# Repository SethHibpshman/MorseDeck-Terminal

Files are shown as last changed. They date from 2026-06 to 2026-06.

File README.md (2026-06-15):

# MorseDeck Terminal

> A standalone Morse code keyer and trainer built on the ESP32-S3, featuring real-time decoding, four keying modes, a rotary settings menu, and T9-style keyboard replay.

<p align="center">
  <a href="https://youtu.be/P0Hb8axpHqs">
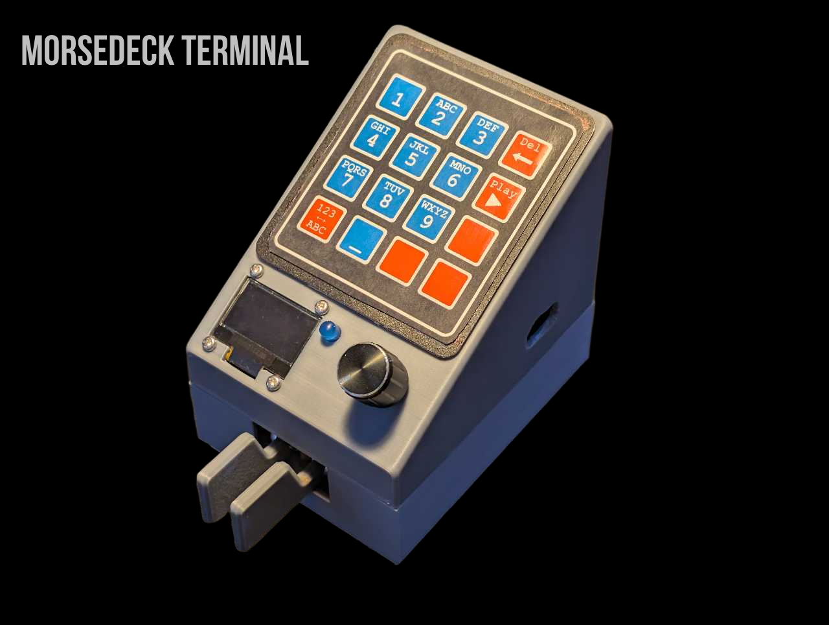
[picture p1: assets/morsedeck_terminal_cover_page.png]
Watch demo
    
  </a>
</p>

<p align="center">
  <a href="https://youtu.be/P0Hb8axpHqs">▶️ Watch the Full Demo</a>
</p>

> Full build documentation, hardware reference, and software notes are in the [project wiki](../../wiki). For an account of the technical challenges, design decisions, and lessons learned, see [Design Reflections](../../wiki/5.-Design-Reflections).

## Table of Contents

- [Overview](#overview)
- [Functionality](#functionality)
  - [Operating Modes](#operating-modes)
  - [Keying Modes](#keying-modes)
  - [Morse Decoding](#morse-decoding)
  - [Keyboard Replay Mode](#keyboard-replay-mode)
  - [Settings Menu](#settings-menu)
- [System Design](#system-design)
  - [Hardware](#hardware)
  - [PCB Design](#pcb-design)
  - [Software](#software)
- [Bill of Materials](#bill-of-materials)
- [Author](#author)
- [AI Disclosure](#ai-disclosure)
- [License](#license)

## Overview

MorseDeck Terminal is a fully self-contained Morse code keyer and trainer built on the ESP32-S3 and programmed in MicroPython. The device supports professional-grade iambic keying with automatic real-time decoding, a rotary encoder settings interface, multi-tap keyboard input, and serial output to an external display, all running on a custom PCB in a 3D-printed enclosure.

The project was designed and built from scratch for **EENG 163: Introduction to Embedded Systems** at Eastern Washington University, covering real-time signal generation, hardware input handling, OLED display rendering, and inter-device communication.

## Functionality

### Operating Modes

The device has three selectable operating modes, accessible from the settings menu:

| Mode | Description |
|---|---|
| **Sandbox** | Free-form keying with live decoding on the OLED |
| **Keyboard Replay** | Type text via keypad and play it back as Morse |
| **Debug** | Live readout of paddle state, encoder pins, keypad input, and memory |

### Keying Modes

Four keying styles are supported, covering both traditional and modern paddle techniques:

| Mode | Behavior |
|---|---|
| **Iambic A** | Alternates dit/dah while both paddles are held; stops on release |
| **Iambic B** | Same as A, but sends one extra element after both paddles are released |
| **Ultimatic** | Last-pressed paddle wins when both are held simultaneously |
| **Straight Key** | Either paddle held produces a continuous tone |

### Morse Decoding

Gap detection runs automatically in the background and scales with the live WPM setting:

- After **3x the dit duration** of paddle idle time, a letter space is inserted and the buffered sequence is decoded to the OLED
- After **7x the dit duration**, the space is upgraded to a word break

### Keyboard Replay Mode

Text can be entered using the 4x4 keypad with T9-style multi-tap input, following a standard phone keyboard layout. The device encodes the typed text to Morse in real time, displays it on the OLED, and plays it back through the buzzer on command.

| Key | Action |
|---|---|
| A | Backspace |
| B | Play current text as Morse |

### Settings Menu

Hold the rotary encoder button for **2 seconds** to open the settings menu. Short-press to enter edit mode on any item, then rotate to adjust.

| Setting | Options |
|---|---|
| Mode | Sandbox, Keyboard Replay, Debug |
| Keying Mode | Iambic A, Iambic B, Ultimatic, Straight Key |
| Volume | 0-10 |
| LED | Enabled / Disabled |
| Decoding | Enabled / Disabled |
| About | Scrolling credits page |
| Reset | Hard resets the device |

Additional behaviors include a typewriter-style boot screen on startup and a bouncing-logo screensaver after 60 seconds of inactivity.

## System Design

### Hardware

| Component | Details |
|---|---|
| Microcontroller | ESP32-S3 |
| Display | SSD1306 128x64 OLED (SoftI2C) |
| Paddles | 2x momentary buttons (Dit / Dah) |
| Keypad | 4x4 membrane matrix keypad |
| Rotary Encoder | CLK, DT, SW with long-press menu activation |
| Buzzer | Piezo PWM buzzer |
| LED | Single external indicator LED |

> Full pin mapping and wiring notes are in the [Hardware Reference](../../wiki/3.-Hardware-Reference) wiki page.

### PCB Design

Designed in KiCad. All project files are in [`/hardware/kicad_project_files`](/hardware/kicad_project_files).

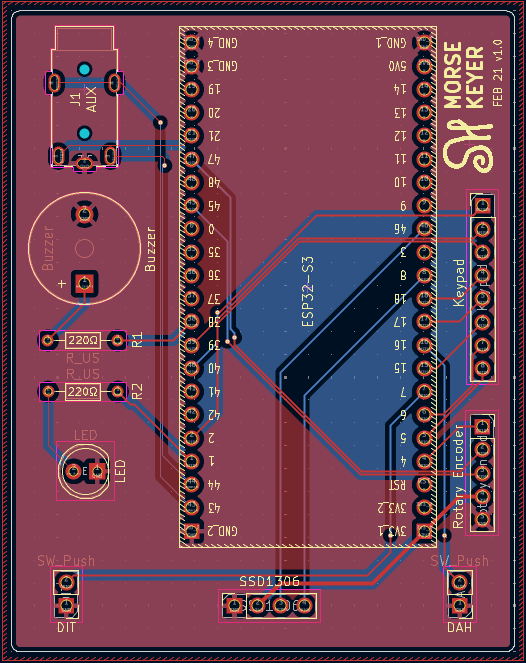
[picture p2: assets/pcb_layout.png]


### Software

Written entirely in **MicroPython** as a single-file application.

**Dependencies:** `ssd1306`, `gfx`, `keypad`, `urandom`

```
main.py    # Full application: hardware init, all functions, main loop
```

> Code structure, dependencies, and configuration details are in the [Software Reference](../../wiki/4.-Software-Reference) wiki page.

## Bill of Materials

| Item | Qty | Unit | Total |
|---|---|---|---|
| [ESP32-S3 Dev Board](https://a.co/d/08OKpdB2) | 1 | $6.40 | $6.40 |
| SSD1306 OLED 128x64 | 1 | $3.00 | $3.00 |
| Rotary Encoder | 1 | $3.00 | $3.00 |
| 4x4 Membrane Keypad | 1 | $1.60 | $1.60 |
| PCBs | 1 | - | $5.00 |
| Piezo Buzzer (Active) | 1 | $0.35 | $0.35 |
| Resistors | - | - | $0.12 |
| LED | 1 | $0.03 | $0.03 |
| 3D-printed enclosure | 1 | - | $0.00 |
| **Grand Total** | | | **$19.50** |

> - Unit costs reflect bulk purchasing; individual retail prices may be higher.
> - 3D printing assumes university or personal printer access.
> - PCB cost assumes overseas fabrication.

## Author

**Seth Hibpshman**  
Student of Electrical Engineering, Eastern Washington University

## AI Disclosure
_AI (LLM) tools were used for quality assurance review of the firmware and in the drafting and editing of this README and wiki documentation; all code was written by hand._

## License

[GNU General Public License v3.0](LICENSE)

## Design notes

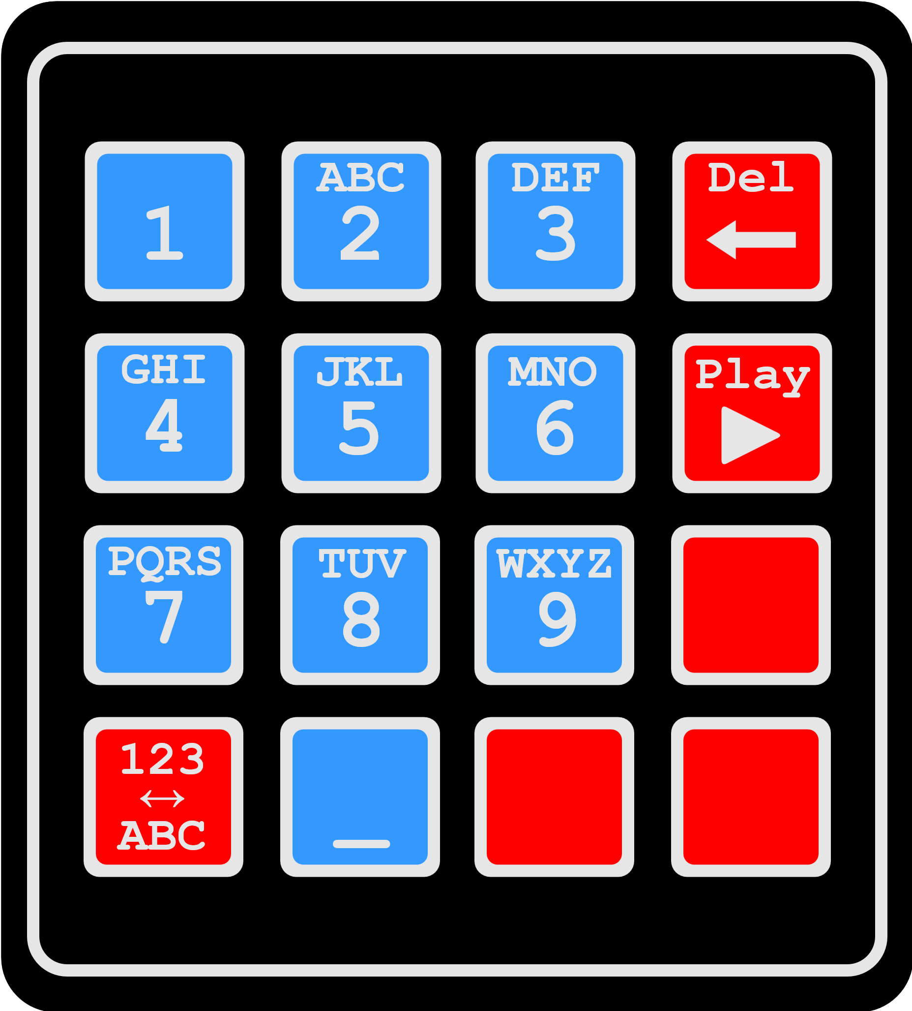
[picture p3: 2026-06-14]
assets/4x4_keypad_art/keypad 4x4.png

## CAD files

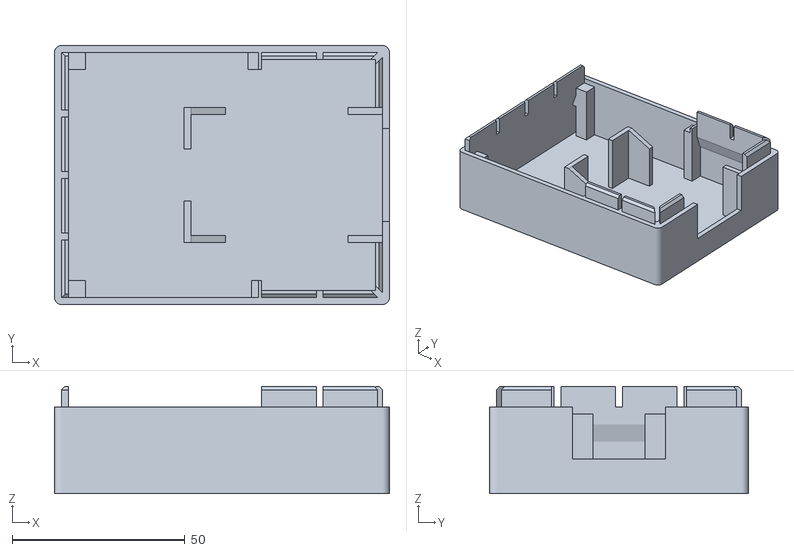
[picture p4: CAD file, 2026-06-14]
hardware/enclosure_model_files/MorseDeck Terminal Bottom Shell.stl
97.0 x 75.0 x 31.0

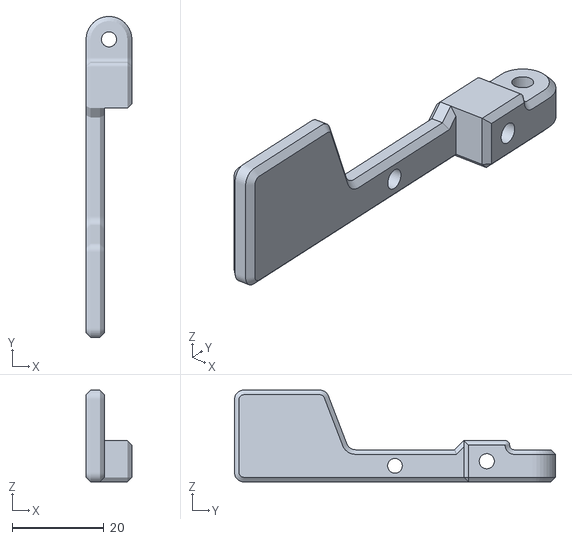
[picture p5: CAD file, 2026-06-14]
hardware/enclosure_model_files/paddle_assembly/paddles-right_lever_nospacer.stl
10.0 x 70.0 x 20.0

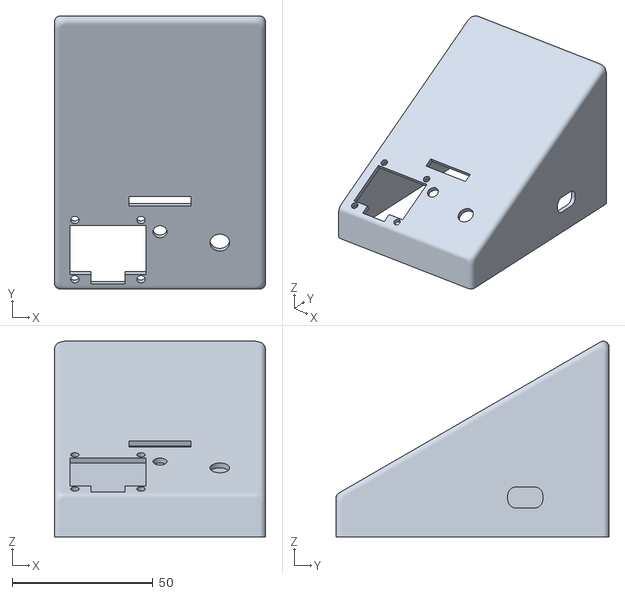
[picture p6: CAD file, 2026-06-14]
hardware/enclosure_model_files/MorseDeck Terminal Top Shell.stl
75.0 x 97.0 x 69.5

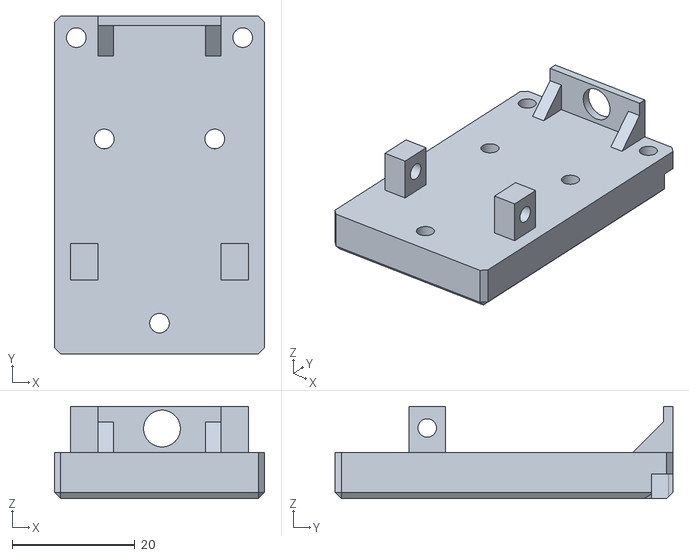
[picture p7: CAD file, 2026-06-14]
hardware/enclosure_model_files/paddle_assembly/paddles-base.stl
34.2 x 55.0 x 15.0

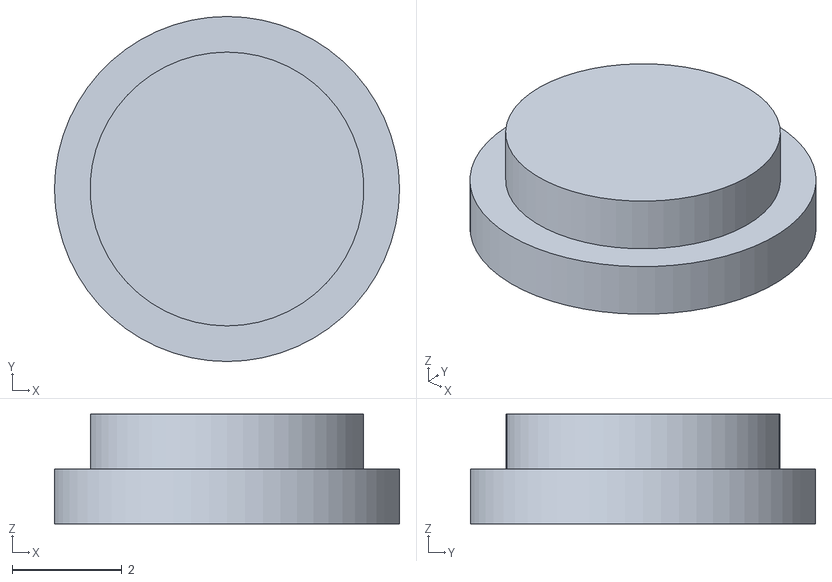
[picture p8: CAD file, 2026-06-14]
hardware/enclosure_model_files/paddle_assembly/paddles-spring_clip.stl
6.30 x 6.30 x 2.00

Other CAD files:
hardware/enclosure_model_files/paddle_assembly/paddles-left_lever_nospacer.stl
hardware/enclosure_model_files/Morse Keyer Top Shell.f3d
hardware/enclosure_model_files/MorseDeck Terminal Bottom Shell.f3d

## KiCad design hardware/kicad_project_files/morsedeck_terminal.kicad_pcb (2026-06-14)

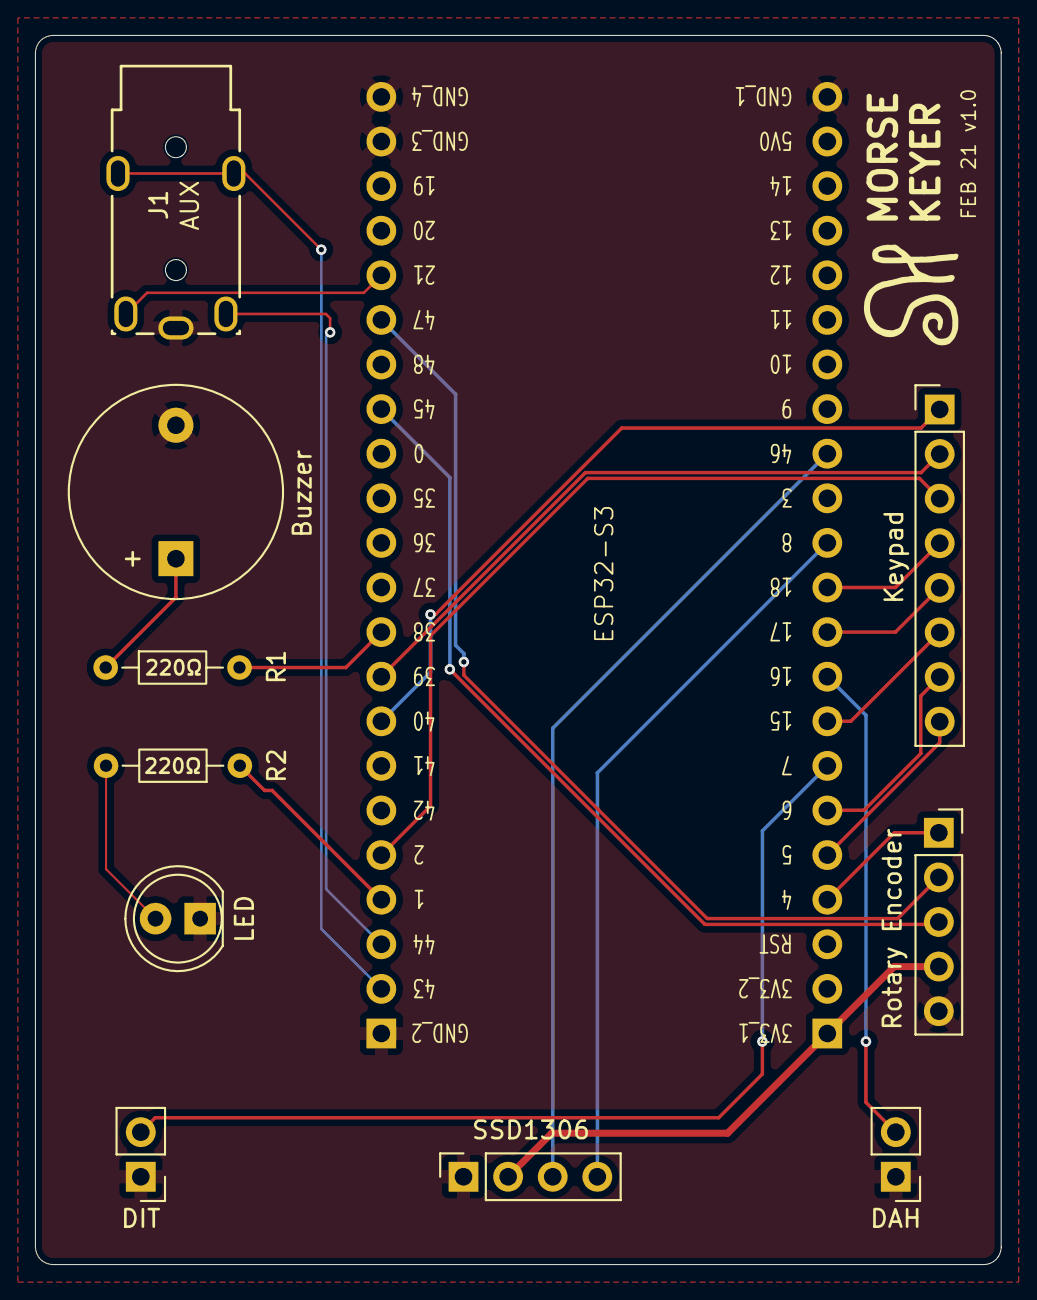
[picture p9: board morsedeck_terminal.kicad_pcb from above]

Board: 4 copper layers, 55.0 x 70.0 mm, 11 parts (0 on the bottom side), 24 nets.

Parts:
Buzzer: Buzzer_12x9.5RM7.6
DAH: SW_Push; PinHeader_1x02_P2.54mm_Vertical
DIT: SW_Push; PinHeader_1x02_P2.54mm_Vertical
ESP32-S3: ESP32-S3 Mount
J1: 3.5mm Aux Jack; 54-00174_TEN
Keypad: PinHeader_1x08_P2.54mm_Vertical
LED: LED; LED_D5.0mm
R1, R2: R_US; R_Axial_DIN0204_L3.6mm_D1.6mm_P7.62mm_Horizontal
Rotary Encoder: PinSocket_1x05_P2.54mm_Vertical
SSD1306: PinSocket_1x04_P2.54mm_Vertical

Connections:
+3V3: ESP32-S3.3V3_1 (3V3), Rotary Encoder.4 (+), SSD1306.2 (VCC)
/GPIO1: ESP32-S3.1 (GPIO1), R2.1
/GPIO2: ESP32-S3.2 (GPIO2), Keypad.3 (Col_2)
/GPIO4: ESP32-S3.4 (GPIO4), Rotary Encoder.1 (CLK)
/GPIO5: ESP32-S3.5 (GPIO5), Keypad.8 (Row_1)
/GPIO6: ESP32-S3.6 (GPIO6), Keypad.7 (Row_2)
/GPIO7: DIT.2, ESP32-S3.7 (GPIO7)
/GPIO8: ESP32-S3.8 (GPIO8), SSD1306.4 (SDA)
/GPIO15: ESP32-S3.15 (GPIO15), Keypad.6 (Row_3)
/GPIO16: DAH.2, ESP32-S3.16 (GPIO16)
/GPIO17: ESP32-S3.17 (GPIO17), Keypad.5 (Row_4)
/GPIO18: ESP32-S3.18 (GPIO18), Keypad.4 (Col_1)
/GPIO21: ESP32-S3.21 (GPIO21), J1.1 (Sleeve_SW)
/GPIO38: ESP32-S3.38 (GPIO38), R1.2
/GPIO39: ESP32-S3.39 (GPIO39), Keypad.2 (Col_3)
/GPIO40: ESP32-S3.40 (GPIO40), Keypad.1 (Col_4)
/GPIO45: ESP32-S3.45 (GPIO45), Rotary Encoder.3 (SW)
/GPIO46: ESP32-S3.46 (GPIO46), SSD1306.3 (SCL)
/GPIO47: ESP32-S3.47 (GPIO47), Rotary Encoder.2 (DT)
/RX/GPIO44: ESP32-S3.44 (RX/GPIO44), J1.3 (Ring)
/TX/GPIO43: ESP32-S3.43 (TX/GPIO43), J1.4 (Tip)
GND: Buzzer.2 (-), DAH.1, DIT.1, ESP32-S3.GND_1 (GND), ESP32-S3.GND_2 (GND), ESP32-S3.GND_3 (GND), ESP32-S3.GND_4 (GND), J1.2 (Sleeve), LED.1 (K), Rotary Encoder.5 (GND), SSD1306.1 (GND)
unnamed: Buzzer.1 (+), R1.1
unnamed: LED.2 (A), R2.2

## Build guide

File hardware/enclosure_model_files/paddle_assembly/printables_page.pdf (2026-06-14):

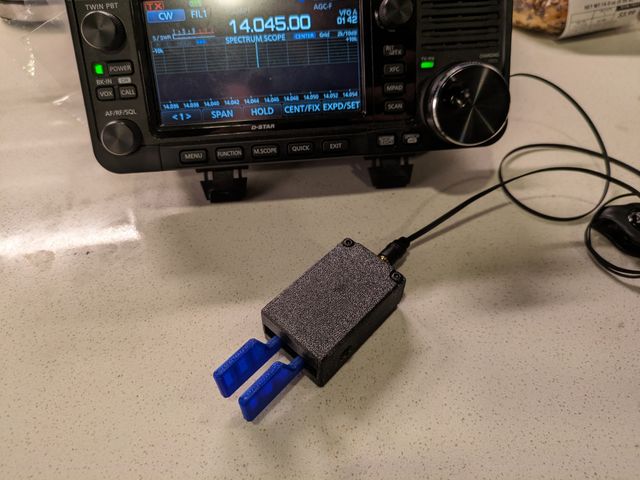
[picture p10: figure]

1.24 hrs

2 pcs

f

0.20 mm

k

0.40 mm

h

PET

25 g

d

Prusa MK4

## Summary

Medium sized Iambic Paddle perfect for both Shack and portable CW Operation

Gadgets (https://printables.com/model?categoryId=21) > Other Gadgets (https://printables.com/model?categoryId=43)

Tags: | paddle | radio | hamradio | amateurradio | morse
morsecode | cw | iambic

This is my take on an Iambic Paddle for CW (Morse Code) Operation. It takes inspiration from the CWMorse Pocket Paddles but is smaller and can be made at home!

I Recommend printing this in PETG for durability, but you can print this in PLA if you wish. If you print in PETG, add a brim for the levers and add a support enforcer for the two corners of the base and cover. Do not add supports to the other screw holes on the base since they will be hard to remove. (If that doesn't make any sense then open the 3mf file in PrusaSlicer to see what I mean)

Jonathan Kayne (https://printables.com/@JonathanKayne)

## Iambic CW Morse Code Paddle by KM4CFT

VIEW IN BROWSER (https://printables.com/model/653813-iambic-cw-morse-code-paddle-by-km4cft)

updated 2. 9. 2024 | published 2. 9. 2024

Want to purchase this as a kit? We now have it available for sale on https://HamGadgets.com

HARDWARE NEEDED:

1x - 3.5mm Audio Jack (https://a.co/d/icm4Hdr)
3x - M3x6mm pan head screw 2x - M3x8mm pan head screw 1x - M3x10mm pan head screw 2x - M3x16mm pan head screw 2x - M3x20mm pan head screw 6x - M3 Hex Nut
2x - M3 Nylock Nut
1x - 10mm M3 Standoff
2x - M3 Washer
3x - M3 Solder Lug (https://www.amazon.com/dp/B07VHM1Q7W)
1x - 0.5x6x15mm Compression Spring 1x - 1.5" piece of wire for ground
2x - 2" piece of wire for two contacts OPTIONAL: 4x - 1⁄4" Neodymium Magnets (https://www.amazon.com/dp/B0BBWH44YT)

ASSEMBLY:

Print all the parts! You will need 1 of each (Base, Cover, Left Lever, Right Lever, Spring Clip)
Solder the three pieces of wire to the solder lugs and the audio jacks. using one of the screws, pull an M3 hex nut into the spring hole (the lager hole near the hinge point) on the Left Lever.
Insert the audio jack into the hole on the base. The center tab should be on the bottom.
On each of the levers insert a M3x6 screw onto the flat side. this will be the contact for the levers. Connect the solder lugs to the outside of these screws and secure with a nut.
Push the two M3x16 screws up from the bottom of the base plate where the hinge holes are.
Place a washer on the two M3x16 screws then attach the two Levers. Secure the screws with nylock nuts. Carefully adjust these so that they allow the levers to easily rotate but not wobble too much. Insert two M3x8 screws into the distance adjustment pillars.
Insert an M3x10 screw into the hole for the spring tension adjustment. Only thread it partially.
Tilt the paddle on its side and carefully place the Spring Clip into the hole.
Using tweezers, squeeze the spring and secure it between the two spring holes. This can be a bit annoying but it is possible!
Take an M3 Hex nut and push it into the hole under the center pillar hole.

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
Screw the M3 Standoff into place. Adjust so that the flat edges are normal to the contacts.
Secure the center wire to the standoff with a M3x6 screw.
Make some slight adjustments to the distance screws and spring tension screw. Connect to a transceiver or practice oscillator and make sure the paddle is working!
Take the cover and seal up the key with two M3x20 screws and two M3 nuts.
Enjoy your new Iambic Paddle!

A more in depth assembly guide can also be found on https://www.radiodan.com/pdf

Here are some helpful pictures:

14.

15.
16.

17.

18.

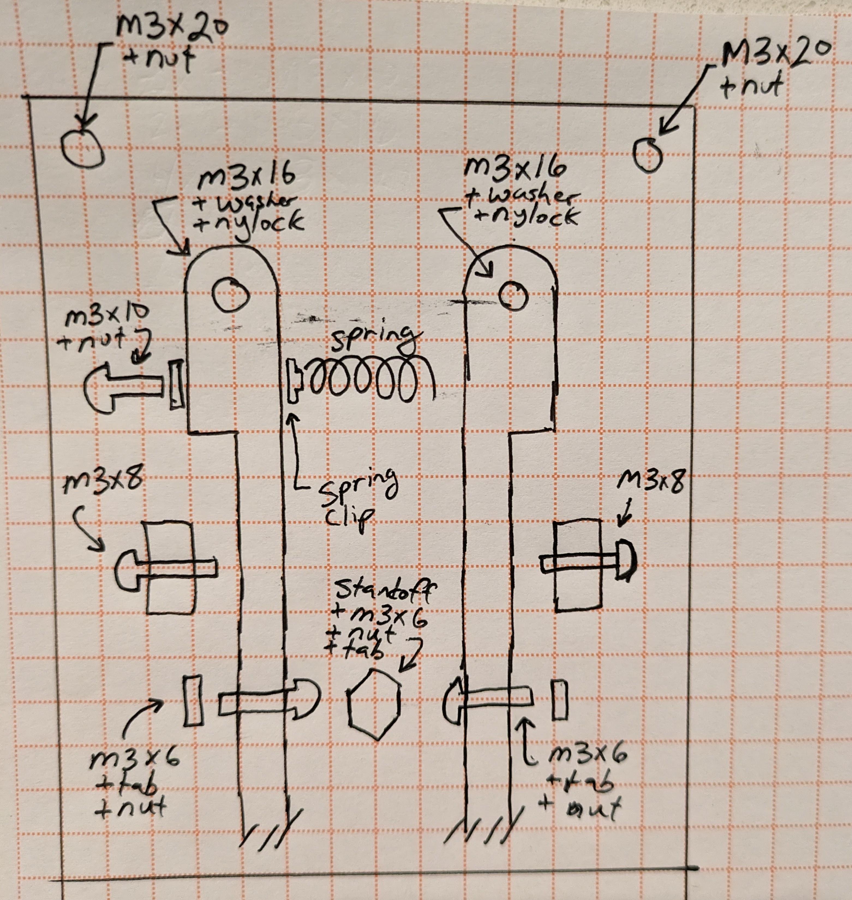
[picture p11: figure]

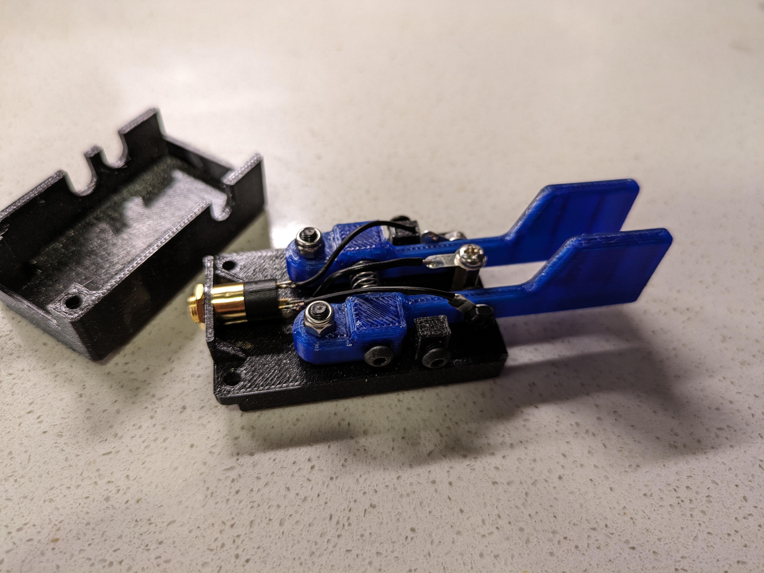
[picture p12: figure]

## Model files

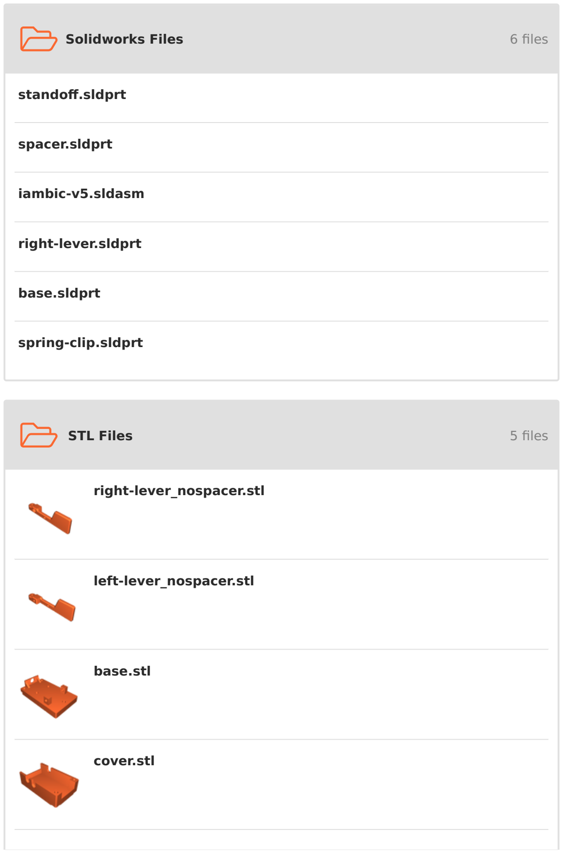
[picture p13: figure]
Solidworks Files; 6 files; STL Files; 5 files; standoff.sldprt; spacer.sldprt; iambic-v5.sldasm; right-lever.sldprt; base.sldprt; spring-clip.sldprt; right-lever_nospacer.stl; left-lever_nospacer.stl; base.stl; cover.stl

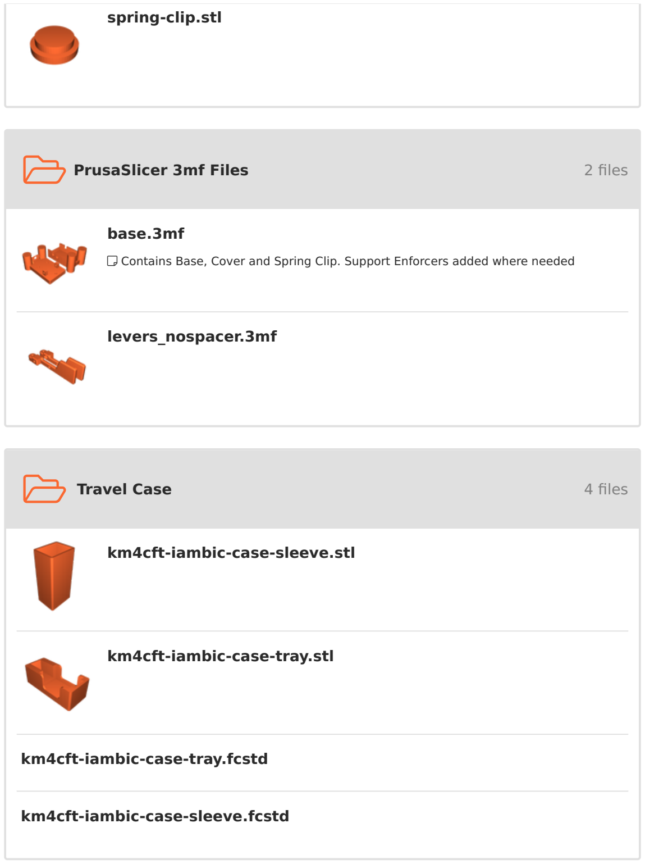
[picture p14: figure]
PrusaSlicer 3mf Files; 2 files; Travel Case; 4 files; spring-clip.stl; base.3mf; levers_nospacer.3mf; km4cft-iambic-case-sleeve.stl; km4cft-iambic-case-tray.stl; km4cft-iambic-case-tray.fcstd; km4cft-iambic-case-sleeve.fcstd

- Contains Base, Cover and Spring Clip. Support Enforcers added where needed

## Print files

h PET k 0.40 mm f 0.20 mm 0.44 hrs 7 g d Prusa MK4

h PET k 0.40 mm f 0.20 mm 0.80 hrs 18 g d Prusa MK4

## License

This work is licensed under a
Creative Commons (4.0 International License)

Attribution-NonCommercial (http://creativecommons.org/licenses/by-nc/4.0/)

✖ | Sharing without ATTRIBUTION
✔ | Remix Culture allowed
✖ | Commercial Use
✖ | Free Cultural Works
✖ | Meets Open Definition

levers_nospacer_04n_02mm_petg_mk4is_26m.gcode

case_04n_02mm_petg_mk4is_48m.gcode

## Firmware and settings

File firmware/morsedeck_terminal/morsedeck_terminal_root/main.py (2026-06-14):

"""
Morse Keyer & Trainer — ESP32-S3
=================================
A MicroPython-based morse code keyer and trainer. Handles paddle input,
buzzer output, OLED display, rotary encoder settings menu, UART TX,
and automatic morse decoding.

Hardware:
    - ESP32-S3 microcontroller (MicroPython)
    - SSD1306 128x64 OLED via SoftI2C
    - Buzzer on Pin 38
    - Dit paddle on Pin 7, Dah paddle on Pin 16
    - Rotary encoder: CLK=4, DT=47, SW=45
    - External LED on Pin 1
    - UART1 TX=17, RX=18 at 115200 baud

Classes:
    None — procedural style with grouped functions

Author: Seth Hibpshman
Course: EENG 163 Final Project
License: GNU GPL v3
"""

from machine import Pin, SoftI2C, PWM, reset, UART
import ssd1306
import gfx
from time import sleep, ticks_ms, ticks_diff
import gc
import urandom

# <><><><><><><><><><><><><><><><><><><><><><>
# SETUP
# <><><><><><><><><><><><><><><><><><><><><><>

# HARDWARE ##############################

# UART
uart = UART(1, baudrate=115200, tx=17, rx=18)
last_sent_morse = ""

# Buzzer
buz = PWM(Pin(38))
buz.freq(700)
buz.duty_u16(0)
buz_vol_list = [0, 500, 1200, 2500, 5000, 9000, 15000, 23000, 33000, 46000, 58000]

# Paddles
dit_in = Pin(7,  Pin.IN, Pin.PULL_UP)
dah_in = Pin(16, Pin.IN, Pin.PULL_UP)

# Rotary Encoder
clk = Pin(4,  Pin.IN, Pin.PULL_UP)
dt  = Pin(47, Pin.IN, Pin.PULL_UP)
sw  = Pin(45, Pin.IN, Pin.PULL_UP)
last_clk = clk.value()
rotary_hold_start = 0       # Measures how long the rotary encoder button is held
settings_menu_open = False  # Tracks if settings menu is open — starts closed

# External LED
led = Pin(1, Pin.OUT)

# SSD1306 OLED
i2c     = SoftI2C(scl=Pin(46), sda=Pin(8))
oled    = ssd1306.SSD1306_I2C(128, 64, i2c)
oled_gfx = gfx.GFX(128, 64, oled.pixel)

# SETTINGS MENU ##############################
settings_menu_items = [
    # Tuples of (display label, key). Headings skip selection and editing.
    ("MODAL CONFIG",  "heading"),
    ("Mode",          "mode"),
    ("BEHAVIOR",      "heading"),
    ("Keying Mode",   "keying_mode"),
    ("Volume",        "volume"),
    ("LED",           "led"),
    ("Decoding",      "decoding"),
    ("OTHER",         "heading"),
    ("About",         "about"),
    ("Reset",         "reset"),
]

settings = {
    # Default values for each editable setting
    "wpm":         10,
    "mode":         3,
    "volume":       5,
    "led":       True,
    "keying_mode":  0,
    "decoding":  True,
}

settings_menu_selected          = 0   # Currently highlighted menu item index
settings_menu_scroll            = 0   # Top-most visible menu item index (for scrolling)
settings_menu_line_height       = 10  # Pixels per menu row
settings_menu_max_visible_lines = 6   # How many rows fit on screen at once
settings_menu_in_scrollable_menu = 0  # Mode constant: browsing the menu
settings_menu_in_editing_menu    = 1  # Mode constant: editing a value
settings_menu_current_menu_mode  = settings_menu_in_scrollable_menu  # Start in scroll mode

about_scroll_offset = 0   # Current scroll position in the about screen (pixels)
about_scroll_speed  = 8   # Pixels scrolled per update call

# SOFTWARE ##############################

morse_oled_content = '/'  # Accumulates all keyed morse symbols for display and decoding
decoded_text       = ''   # Human-readable decoded output built from morse_oled_content
max_characters     = 16   # Max chars shown on OLED per row (SSD1306 is 16 chars wide at 8px)

# Sleep
sleep_enabled    = True         # Can be toggled in settings
device_sleeping  = False        # Tracks current sleep state
sleep_timeout_ms = 60000        # Idle milliseconds before sleeping (60 seconds)
last_input_time  = ticks_ms()   # Timestamp of last user activity

# <><><><><><><><><><><><><><><><><><><><><><>
# FUNCTIONS
# <><><><><><><><><><><><><><><><><><><><><><>

def do_a_dit():
    """Sound a dit, append '.' to morse content, then observe inter-element gap."""
    global morse_oled_content, last_morse_end_time
    buz.duty_u16(buz_volume)
    led.value(settings["led"])
    morse_oled_content = morse_oled_content + '.'
    draw_current_mode()
    sleep(dit_t)
    buz.duty_u16(0)
    led.value(0)
    sleep(gap_t)
    last_morse_end_time = ticks_ms()

def do_a_dah():
    """Sound a dah, append '-' to morse content, then observe inter-element gap."""
    global morse_oled_content, last_morse_end_time
    buz.duty_u16(buz_volume)
    led.value(settings["led"])
    morse_oled_content = morse_oled_content + '-'
    draw_current_mode()
    sleep(dah_t)
    buz.duty_u16(0)
    led.value(0)
    sleep(gap_t)
    last_morse_end_time = ticks_ms()

def draw_current_mode():
    """Dispatch display refresh to the draw function for the active mode."""
    current_mode = settings["mode"]
    if current_mode == "sandbox":
        draw_sandbox_mode(morse_oled_content)
    elif current_mode == "telegraph":
        draw_telegraph_mode(morse_oled_content)

def play_morse_string(morse_str):
    """
    Play back a pre-built morse string through the buzzer.

    Handles '.', '-', ' ' (letter break), and '/' (word break) symbols.
    Decodes and updates the display after each separator.

    Parameters
    ----------
    morse_str : str
        A morse string e.g. '... --- ...' to play back sequentially.

    Returns
    -------
    None
    """
    global morse_oled_content, decoded_text
    n = len(morse_str)
    for i, symbol in enumerate(morse_str):
        last_symbol = (i == n - 1)

        if symbol == '.':
            do_a_dit()
        elif symbol == '-':
            do_a_dah()
        elif symbol == ' ':
            # Letter break — decode the last letter and insert a space
            morse_decoder()
            morse_oled_content += ' '
            draw_sandbox_mode(morse_oled_content)
            sleep(letter_break_t)
        elif symbol == '/':
            # Word break — decode, insert slash, add decoded space
            morse_decoder()
            morse_oled_content += '/'
            decoded_text += ' '
            draw_sandbox_mode(morse_oled_content)
            sleep(word_break_t)

        # Treat the final symbol as a word break
        if last_symbol:
            morse_decoder()
            morse_oled_content += '/'
            decoded_text += ' '
            draw_sandbox_mode(morse_oled_content)
            sleep(word_break_t)

# DISPLAY HELPERS <><><><><><><><><><><><><><><><><><><><><><><><>

def draw_centered(text, center_x, y):
    """
    Draw text centred on a given x coordinate.

    Parameters
    ----------
    text : str
        String to render.
    center_x : int
        Pixel x position to centre the text around.
    y : int
        Pixel y position (top of text).
    """
    width = len(text) * 8
    x = center_x - (width // 2)
    oled.text(text, x, y)

def draw_right_aligned(text, right_x, y):
    """
    Draw text so its right edge sits at right_x.

    Parameters
    ----------
    text : str
        String to render.
    right_x : int
        Pixel x position of the right edge.
    y : int
        Pixel y position (top of text).
    """
    width = len(text) * 8  # 8 pixels per character
    x = right_x - width
    oled.text(text, x, y)

# MODE DRAW FUNCTIONS <><><><><><><><><><><><><><><><><><><><><><><><>

def draw_sandbox_mode(morse_oled_content=None):
    """
    Render the sandbox mode screen.

    Shows the last max_characters of morse content on row 1, and
    optionally the decoded text on row 2 if decoding is enabled.

    Parameters
    ----------
    morse_oled_content : str, optional
        Current morse string to display. Nothing is drawn if None.
    """
    oled.fill(0)
    if morse_oled_content is not None:
        oled.text('Morse:', 0, 0)
        draw_right_aligned((morse_oled_content[-max_characters:]), 128, 12)
        if settings["decoding"] == True:
            draw_right_aligned((decoded_text[-max_characters:]), 128, 24)
    oled.show()

def draw_telegraph_mode(morse_oled_content=None):
    """
    Render the telegraph mode screen.

    Same layout as sandbox but with a 'Telegraph:' heading.

    Parameters
    ----------
    morse_oled_content : str, optional
        Current morse string to display.
    """
    oled.fill(0)
    oled.text('Telegraph:', 0, 0)
    if morse_oled_content:
        draw_right_aligned(morse_oled_content[-max_characters:], 128, 12)
    if settings["decoding"] == True:
        draw_right_aligned(decoded_text[-max_characters:], 128, 24)
    oled.show()

# SETTINGS MENU <><><><><><><><><><><><><><><><><><><><><><><><>

def settings_menu_draw_menu():
    """
    Render the settings menu in either scrollable or editing mode.

    Scrollable mode shows a highlighted list of menu items.
    Editing mode shows the selected item's current value and allows changes.
    Headings are underlined and cannot be selected.
    """
    oled.fill(0)
    global settings_menu_scroll

    # EDITING MENU ########################
    if settings_menu_current_menu_mode == settings_menu_in_editing_menu:
        item  = settings_menu_items[settings_menu_selected]
        label = item[0]
        key   = item[1]

        if key not in ["heading", "about", "reset"]:
            value_of_currently_selected_menu_item = value_to_str(key, settings[key])
            draw_centered(label, 64, 18)
            draw_centered(value_of_currently_selected_menu_item, 64, 36)
        elif key == "about":
            draw_about_screen()
        elif key == "reset":
            device_reset()
        oled.show()
        return

    # SCROLLABLE SETTINGS MAIN MENU ########################
    # Keep heading visible when the first item beneath it is selected
    extra_heading_line = 0
    if settings_menu_selected == 1:
        extra_heading_line = 1

    if settings_menu_selected < settings_menu_scroll + extra_heading_line:
        settings_menu_scroll = settings_menu_selected - extra_heading_line
    elif settings_menu_selected >= settings_menu_scroll + settings_menu_max_visible_lines:
        settings_menu_scroll = settings_menu_selected - settings_menu_max_visible_lines + 1

    # Render only the visible window of items
    for i in range(settings_menu_scroll, min(settings_menu_scroll + settings_menu_max_visible_lines, len(settings_menu_items))):
        pixel_y = (i - settings_menu_scroll) * settings_menu_line_height
        if pixel_y + settings_menu_line_height > 64:
            continue  # Never clip past the bottom of the screen

        item  = settings_menu_items[i]
        label = item[0]
        key   = item[1]

        if key == "heading":
            oled.text(label, 4, pixel_y + 1, 1)
            oled_gfx.fill_rect(4, pixel_y + 9, len(label) * 8, 1, 1)  # Underline
        else:
            if i == settings_menu_selected:
                # Highlight selected item: white bar, black text
                oled_gfx.fill_rect(0, pixel_y + 1, 128, settings_menu_line_height - 2, 1)
                oled.text(label, 12, pixel_y + 1, 0)
            else:
                oled.text(label, 12, pixel_y + 1, 1)
    oled.show()

def draw_about_screen():
    """
    Render the scrolling about/credits screen.

    Scrolls upward on each call by about_scroll_speed pixels.
    Loops back to the start when the end of the credits is reached.
    """
    global about_scroll_offset
    oled.fill(0)
    credits = [
        "Scroll!",
        "", "", "",
        "Morse Keyer &",
        "Trainer",
        "",
        "Created by:",
        "Seth Hibpshman",
        "",
        "EENG 163",
        "Final Project",
        "",
        "Course",
        "Instructor:",
        "S. Rieseberg",
        "",
        "Software:",
        "- MicroPython",
        "- SSD1306 Lib",
        "  - GFX Lib",
        "- PyCharm",
        "- Thonny",
        "",
        "Special Thanks:",
        "- Supporters",
        "- Open Source",
        "  Community",
        "- Instructors",
        "- Family &",
        "  Friends",
        "",
        "License:",
        "GNU GPL v3",
        "", "", "",
        "The End <3 :)",
    ]

    total_height = len(credits) * 8
    y_start = 64 - 8 - about_scroll_offset  # Begin one line above the bottom edge

    for line_number, line_content in enumerate(credits):
        y = y_start + line_number * 8
        if -8 < y < 64:  # Only draw lines that are actually on screen
            oled.text(line_content, 0, y, 1)

    oled.show()
    about_scroll_offset += about_scroll_speed

    # Loop back to the beginning once all credits have scrolled past
    if about_scroll_offset > total_height + 64:
        about_scroll_offset = 0

# MORSE ENGINE <><><><><><><><><><><><><><><><><><><><><><><><>

def morse_decoder():
    """
    Decode the last morse letter in morse_oled_content and append it to decoded_text.

    Finds the most recent '/' or ' ' separator, extracts the symbol after it,
    and looks it up in morse_alph_dictionary. Appends '?' for unknown sequences.
    """
    global decoded_text
    index_last_slash = morse_oled_content.rfind('/')
    index_last_space = morse_oled_content.rfind(' ')
    last_break_index = max(index_last_slash, index_last_space)

    last_morse_letter = morse_oled_content[last_break_index + 1:].strip()

    if last_morse_letter:
        if morse_alph_dictionary.get(last_morse_letter):
            decoded_text = decoded_text + morse_alph_dictionary[last_morse_letter]
        else:
            decoded_text = decoded_text + '?'  # Unknown sequence

def gap_checker():
    """
    Detect letter and word gaps between paddle presses and insert separators.

    Monitors idle time since the last paddle activity. If idle exceeds
    letter_break_t a space is inserted; if it further exceeds word_break_t
    the space is upgraded to a '/'.
    """
    global morse_oled_content, idle_start_time, letter_space_happened, word_space_happened, decoded_text

    if dit_val == False and dah_val == False:
        # No paddle activity — start or continue counting idle time
        if idle_start_time == 0:
            idle_start_time = current_time
        idle_time = ticks_diff(current_time, idle_start_time)

        # Insert letter space after letter_break_t milliseconds
        if idle_time >= int(letter_break_t * 1000) and letter_space_happened == False:
            morse_decoder()
            morse_oled_content = morse_oled_content + ' '
            draw_sandbox_mode(morse_oled_content)
            letter_space_happened = True
            word_space_happened   = False

        # Upgrade letter space to word break after word_break_t milliseconds
        if letter_space_happened == True and word_space_happened == False:
            if idle_time >= int((word_break_t) * 1000):
                if morse_oled_content and morse_oled_content[-1] == ' ':
                    morse_oled_content = morse_oled_content[:-1] + '/'
                    decoded_text = decoded_text + ' '
                draw_sandbox_mode(morse_oled_content)
                word_space_happened = True
    else:
        # Paddle active — reset all gap tracking
        idle_start_time       = 0
        letter_space_happened = False
        word_space_happened   = False

def keying_handler(dit_val, dah_val, current_time):
    """
    Dispatch paddle presses to the correct keying mode logic.

    Supported modes: Iambic A, Iambic B, Ultimatic, Straight Key.
    Also tracks hold start times and release times for each paddle.

    Parameters
    ----------
    dit_val : bool
        True if the dit paddle is currently pressed.
    dah_val : bool
        True if the dah paddle is currently pressed.
    current_time : int
        Current ticks_ms() value.
    """
    global last_d
    global bth_hld, bth_hld_prev
    global dit_hold_start_time, dah_hold_start_time
    global dit_held, dah_held
    global dit_release_time, dah_release_time

    keying_mode = keying_modes[settings["keying_mode"]]

    # BUTTON STATE TRACKING ############################################
    if dit_val == True and dit_held == False:
        dit_hold_start_time = current_time
        dit_held = True
    elif dit_val == False and dit_held == True:
        dit_held = False
        dit_release_time = current_time

    if dah_val == True and dah_held == False:
        dah_hold_start_time = current_time
        dah_held = True
    elif dah_val == False and dah_held == True:
        dah_held = False
        dah_release_time = current_time

    # IAMBIC A ##############################
    if keying_mode == 'Iambic A':
        if dit_val and dah_val:
            if last_d == 'dah':
                do_a_dit(); last_d = 'dit'
            else:
                do_a_dah(); last_d = 'dah'
        elif dit_val:
            do_a_dit(); last_d = 'dit'
        elif dah_val:
            do_a_dah(); last_d = 'dah'

    # IAMBIC B ##############################
    elif keying_mode == 'Iambic B':
        if dit_val and dah_val:
            bth_hld = True
            if last_d == 'dah':
                do_a_dit(); last_d = 'dit'
            else:
                do_a_dah(); last_d = 'dah'
        elif bth_hld_prev == True:
            if last_d == 'dah':
                do_a_dit(); last_d = 'dit'
            else:
                do_a_dah(); last_d = 'dah'
        elif dit_val:
            do_a_dit(); last_d = 'dit'
        elif dah_val:
            do_a_dah(); last_d = 'dah'

        bth_hld_prev = bth_hld
        bth_hld = False

    # ULTIMATIC #############################
    elif keying_mode == 'Ultimatic':
        if dit_val and dah_val:
            if dit_hold_start_time < dah_hold_start_time:
                do_a_dah()
            elif dit_hold_start_time > dah_hold_start_time:
                do_a_dit()
        elif dit_val:
            do_a_dit(); last_d = 'dit'
        elif dah_val:
            do_a_dah(); last_d = 'dah'

    # STRAIGHT KEY ##########################
    elif keying_mode == 'Straight Key':
        if dit_val or dah_val:
            buz.duty_u16(buz_volume)
            led.value(settings["led"])
        else:
            buz.duty_u16(0)
            led.value(0)

def core_engine_update(dit_val, dah_val, current_time):
    """
    Run one tick of the morse engine: keying then gap detection.

    Parameters
    ----------
    dit_val : bool
        True if the dit paddle is currently pressed.
    dah_val : bool
        True if the dah paddle is currently pressed.
    current_time : int
        Current ticks_ms() value.
    """
    keying_handler(dit_val, dah_val, current_time)
    gap_checker()

# MODE HANDLERS <><><><><><><><><><><><><><><><><><><><><><><><><><><><><><><>

def sandbox_mode(dit_val, dah_val, current_time):
    """Run the engine and refresh the sandbox display."""
    core_engine_update(dit_val, dah_val, current_time)
    draw_sandbox_mode(morse_oled_content)

def training_mode(dit_val, dah_val, current_time):
    """Run the engine and refresh the training display. (Scoring TBD)"""
    core_engine_update(dit_val, dah_val, current_time)
    draw_sandbox_mode(morse_oled_content)

def telegraph_mode(dit_val, dah_val, current_time):
    """
    Run the engine, transmit morse_oled_content over UART, and refresh display.

    Sends the full current morse string as a UTF-8 newline-terminated
    message on every loop tick for the receiving STM32 LCD display.
    """
    global morse_oled_content, decoded_text, last_sent_morse
    core_engine_update(dit_val, dah_val, current_time)
    uart_message = f'{morse_oled_content}\n'
    uart.write(uart_message.encode('utf-8'))
    last_sent_morse = morse_oled_content
    draw_telegraph_mode(morse_oled_content)

def debug_mode(dit_val, dah_val, current_time):
    """
    Display live diagnostic information — paddle state, encoder pins, memory, clock.

    Parameters
    ----------
    dit_val : bool
        Current dit paddle state.
    dah_val : bool
        Current dah paddle state.
    current_time : int
        Current ticks_ms() value.
    """
    oled.fill(0)

    heading = 'DEBUG MODE:'
    oled.text(f"{heading}", 0, 0)
    oled_gfx.fill_rect(4, 9, len(heading) * 8, 1, 1)  # Underline

    dit_state = "ON" if dit_val else "OFF"
    dah_state = "ON" if dah_val else "OFF"
    oled.text(f"DIT/DAH: {dit_state}/{dah_state}", 0, 12)
    oled.text(f"ENC C:{clk.value()} D:{dt.value()} S:{sw.value()}", 0, 22)

    free = gc.mem_free()
    used = gc.mem_alloc()
    oled.text(f"F:{free // 1024:03d}kB", 0, 44)
    oled.text(f"U:{used // 1024:03d}kB", 64, 44)
    oled.text(f"CLK: {current_time} ms", 0, 56)
    oled.show()

# SETTINGS HELPERS <><><><><><><><><><><><><><><><><><><><><><><><>

def value_to_str(key, menu_value):
    """
    Convert a settings value to a human-readable string for the editing menu.

    Parameters
    ----------
    key : str
        The settings dictionary key (e.g. 'mode', 'volume').
    menu_value : any
        The current value stored for that key.

    Returns
    -------
    str
        Display string for the editing menu (e.g. 'Enabled', 'Sandbox').
    """
    if key == "mode":
        return modes[menu_value]
    if key == "keying_mode":
        return keying_modes[menu_value]
    if key in ["led", "decoding"]:
        return "Enabled" if menu_value else "Disabled"
    return str(menu_value)
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

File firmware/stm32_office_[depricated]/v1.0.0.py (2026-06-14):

"""
Morse RX Display - STM32 + ILI9341 LCD
=======================================
Receives morse code strings over UART and displays the last 20 characters
on a 240x320 ILI9341 LCD. Line 1 is a static label; line 2 updates on RX.

Hardware:
    - STM32 microcontroller (MicroPython)
    - ILI9341 LCD via SPI5
    - UART1 (PA9=TX, PA10=RX) at 115200 baud

Classes:
    DisplayDriver  -- manages LCD rendering for the two-line layout
    MorseReceiver  -- handles UART receive, decoding, and display updates
    
Author: Seth Hibpshman
Course: EENG 163 Final Project
License: GNU GPL v3
"""

from machine import Pin, UART, SPI
from time import sleep
from lcd9341 import LCD9341, color565
from xfglcd_font import XglcdFont


# Display constants <><><><><><><><><><><><><><><><><><><><><><><><>

char_width    = 12
char_height   = 24
display_chars = 20          # max chars across the 240 px screen (240 / 12 = 20)

text_x  = 0
line1_y = 0                 # static label row (y pixel offset)
line2_y = char_height       # dynamic morse row (one char-height below label)

text_w  = char_width * display_chars    # 240 px - full screen width
text_h  = char_height                   # 24 px - one character row height

bg_color     = color565(0,   0,   0)
fg_color     = color565(255, 255, 255)

# Hardware init <><><><><><><><><><><><><><><><><><><><><><><><>

spi      = SPI(5, baudrate=10_000_000)
lcd      = LCD9341(spi, dc=Pin('PD13'), cs=Pin('PC2'), rst=Pin('PC11'))
unispace = XglcdFont('fonts/Unispace12x24.c', 12, 24)


# Classes <><><><><><><><><><><><><><><><><><><><><><><><>

class DisplayDriver:
    """
    Manages the two-line ILI9341 LCD layout.

    Line 1 is a static label drawn once at init.
    Line 2 is a 20-character dynamic field, redrawn only when content changes.

    Attributes
    ----------
    lcd : LCD9341
        The LCD driver instance.
    font : XglcdFont
        The font used for all text rendering.
    last_drawn : str or None
        The last string written to line 2; used to skip redundant redraws.

    Methods
    -------
    update(text):
        Update line 2 with the last 20 characters of text.
    """

    def __init__(self, lcd, font, label):
        """
        Initialise the display, clear it, and draw the static label.

        Parameters
        ----------
        lcd : LCD9341
            Initialised LCD driver object.
        font : XglcdFont
            Font object for rendering text.
        label : str
            Static string drawn once on line 1 (e.g. "Morse RX:").
        """
        self.lcd        = lcd
        self.font       = font
        self.last_drawn = None

        # Clear screen and draw the static label - never redrawn after this
        self.lcd.clear(bg_color)
        self.lcd.draw_text(text_x, line1_y, label, self.font, fg_color)

    def update(self, text):
        """
        Redraw line 2 with the last 20 characters of text.

        Skips all SPI activity if the visible content has not changed,
        minimising scanline artifacts on the slow ILI9341 refresh.

        Parameters
        ----------
        text : str
            The full morse string received so far; only the trailing
            display_chars characters are rendered.

        Returns
        -------
        None
        """
        # Take last 20 chars and pad with spaces to erase leftover glyphs
        snippet = text[-display_chars:]
        while len(snippet) < display_chars:
            snippet = snippet + " "

        # Dirty-check - skip redraw if nothing visible has changed
        if snippet == self.last_drawn:
            return
        self.last_drawn = snippet

        # Clear only the line 2 bounding box, then draw new text
        for row in range(text_h):
            self.lcd.draw_hline(text_x, line2_y + row, text_w, bg_color)
        self.lcd.draw_text(text_x, line2_y, snippet, self.font, fg_color)


class MorseReceiver:
    """
    Reads newline-terminated morse strings from a UART and forwards them
    to a DisplayDriver instance for rendering.

    Attributes
    ----------
    uart : UART
        The MicroPython UART object to read from.
    display : DisplayDriver
        The display instance that renders received messages.
    rx_buf : bytes
        Internal accumulation buffer for incoming UART bytes.
    morse_content : str
        The most recently received (non-empty) morse string.

    Methods
    -------
    poll():
        Read available UART bytes, extract complete lines, and update display.
    """

    def __init__(self, uart, display):
        """
        Bind a UART and a DisplayDriver together.

        Parameters
        ----------
        uart : UART
            Initialised MicroPython UART object (e.g. UART(1, 115200)).
        display : DisplayDriver
            Initialised DisplayDriver that will render received strings.
        """
        self.uart          = uart
        self.display       = display
        self.rx_buf        = b""
        self.morse_content = ""

    def poll(self):
        """
        Non-blocking UART poll - call repeatedly from the main loop.

        Appends any available bytes to the internal buffer, then extracts
        and processes every complete newline-terminated line. Silently
        discards lines that cannot be decoded as UTF-8 or are blank.

        Returns
        -------
        None
        """
        if not self.uart.any():
            return

        self.rx_buf += self.uart.read()

        # Process every complete line in the buffer
        while b"\n" in self.rx_buf:
            line, self.rx_buf = self.rx_buf.split(b"\n", 1)
            try:
                decoded = line.decode('utf-8').strip()
            except UnicodeError:
                continue        # drop malformed bytes

            if decoded:
                self.morse_content = decoded
                self.display.update(self.morse_content)


# Entry point <><><><><><><><><><><><><><><><><><><><><><><><>

display  = DisplayDriver(lcd, unispace, "Morse RX:")
receiver = MorseReceiver(UART(1, 115200), display)

# Brief boot confirmation on line 2, then clear it before live RX begins
display.update("LCD OK")
sleep(1)
display.update("")

# Main loop - poll UART continuously at 10 ms intervals
while True:
    receiver.poll()
    sleep(0.01)

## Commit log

2026-06-14 Morse Keyer ---> MorseDeck Terminal Rebrand
    Rebranded all Morse Keyer titles to MorseDeck Terminal.
    Removed stm32 telegraph features.
    Reorganized project folder structure.
    [Aux Breakout Board.kicad_pcb, Aux Breakout Board.kicad_sch, Morse Keyer.kicad_pcb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]
2026-06-14 Enclosure files
    [Morse Keyer Top Shell.f3d, MorseDeck Terminal Bottom Shell.f3d, MorseDeck Terminal Bottom Shell.stl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]
2026-06-14 Add paddles
    [paddles-base.stl, paddles-left_lever_nospacer.stl, paddles-right_lever_nospacer.stl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]
